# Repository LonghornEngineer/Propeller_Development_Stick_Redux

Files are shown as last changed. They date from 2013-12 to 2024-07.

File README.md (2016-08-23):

LHE_BANNER
***
###Propeller_Development_Stick_Redux
***
**Tiny development board based on the Parallax Propeller.**

More information can be found on the [Propeller Development Stick project page](http://longhornengineer.com/projects/pcb/propeller-development-stick-redux/).

Board Files are for Cadsoft Eagle V6.0+

***
**License Information**

This project is under the [Creative Commons Attribution-ShareAlike 4.0 International License](LICENSE.md). These files are provided with no warranty and should be used at your own risk. 

***

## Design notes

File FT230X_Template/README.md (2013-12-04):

Instructions to flash the FT230X on the Propeller Development Stick.

The FT230X needs to be flashed with the template found on GitHub for the Propeller Development Stick to function correctly.

1. Download and install <a href="http://www.ftdichip.com/Support/Utilities.htm">FT-Prog</a> from FTDI. 

2. Connect the Propeller Development Stick via USB cable and load up FT-Prog.

3. Click "Scan and Parse".

4. Once the FT230X is found right click the name and click "Apply Template". Choose the template you want to apply. 

5. Click "Program Devices"

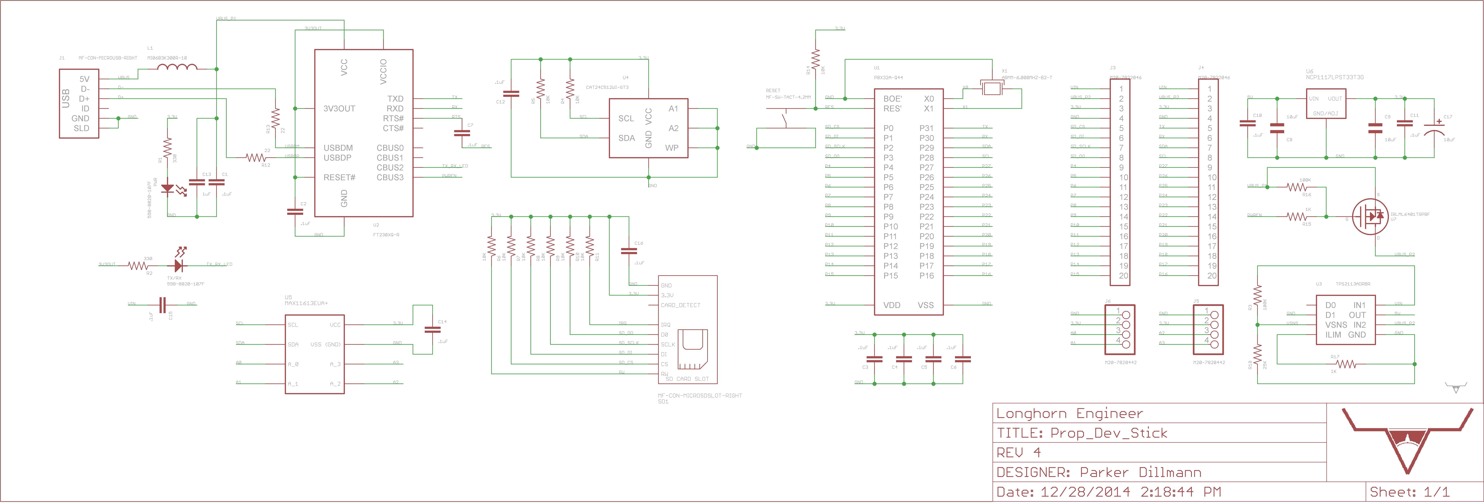
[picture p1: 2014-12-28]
Schematic.png

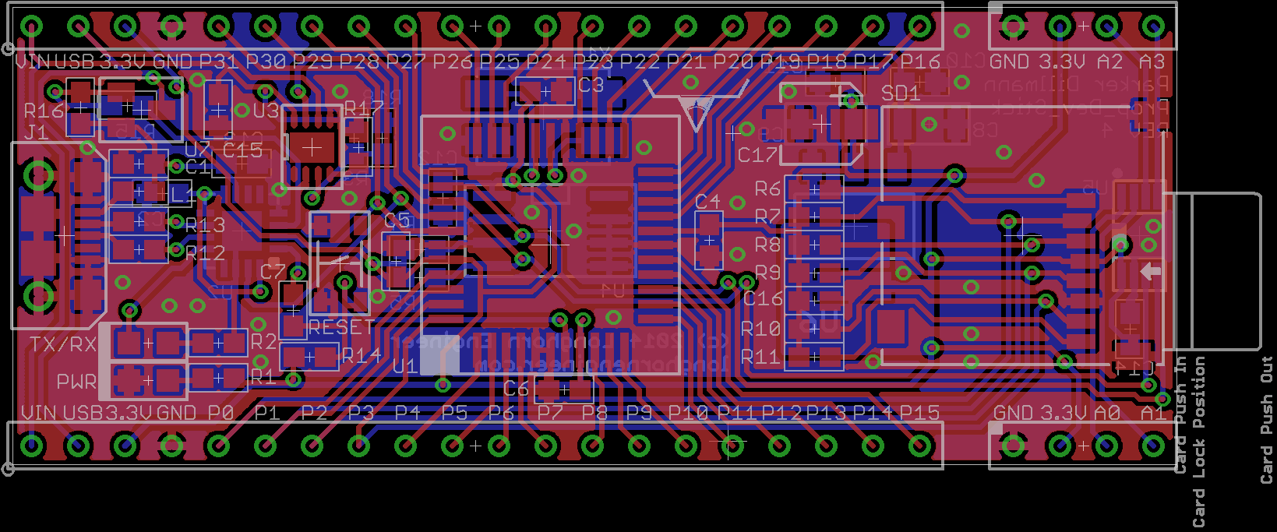
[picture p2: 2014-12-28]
Layout.png

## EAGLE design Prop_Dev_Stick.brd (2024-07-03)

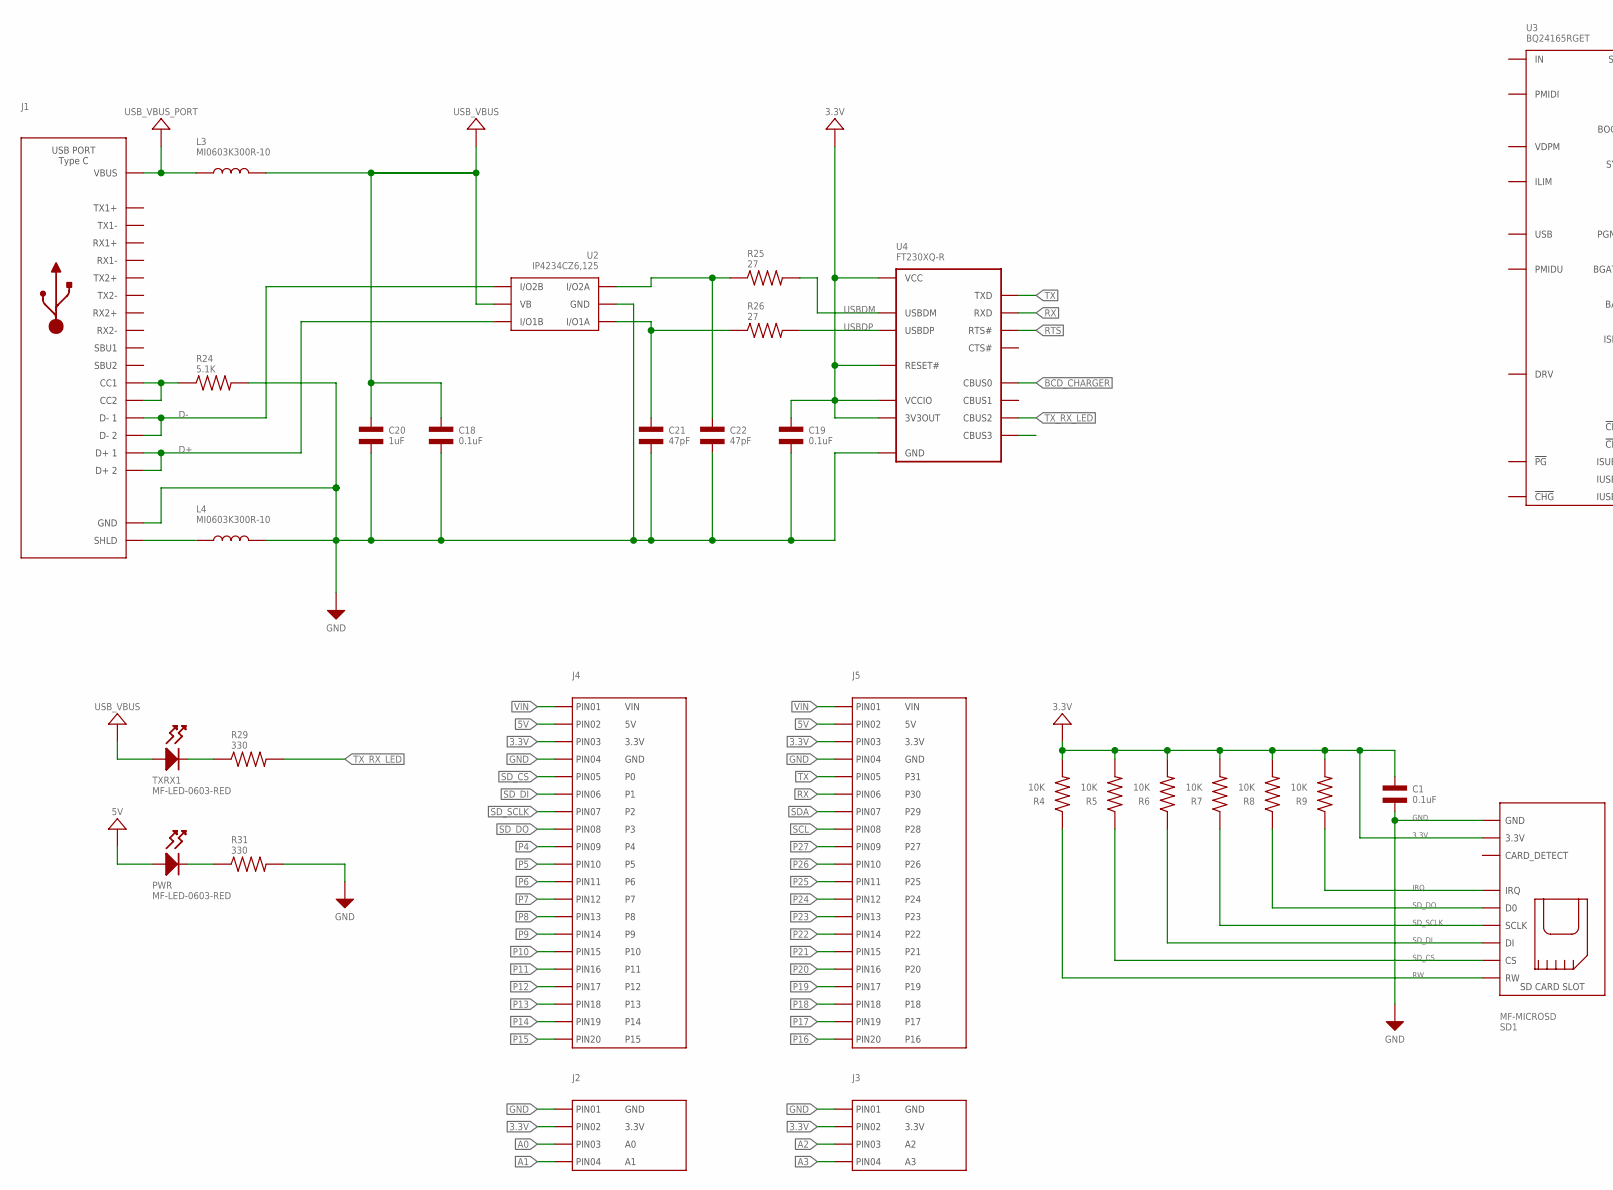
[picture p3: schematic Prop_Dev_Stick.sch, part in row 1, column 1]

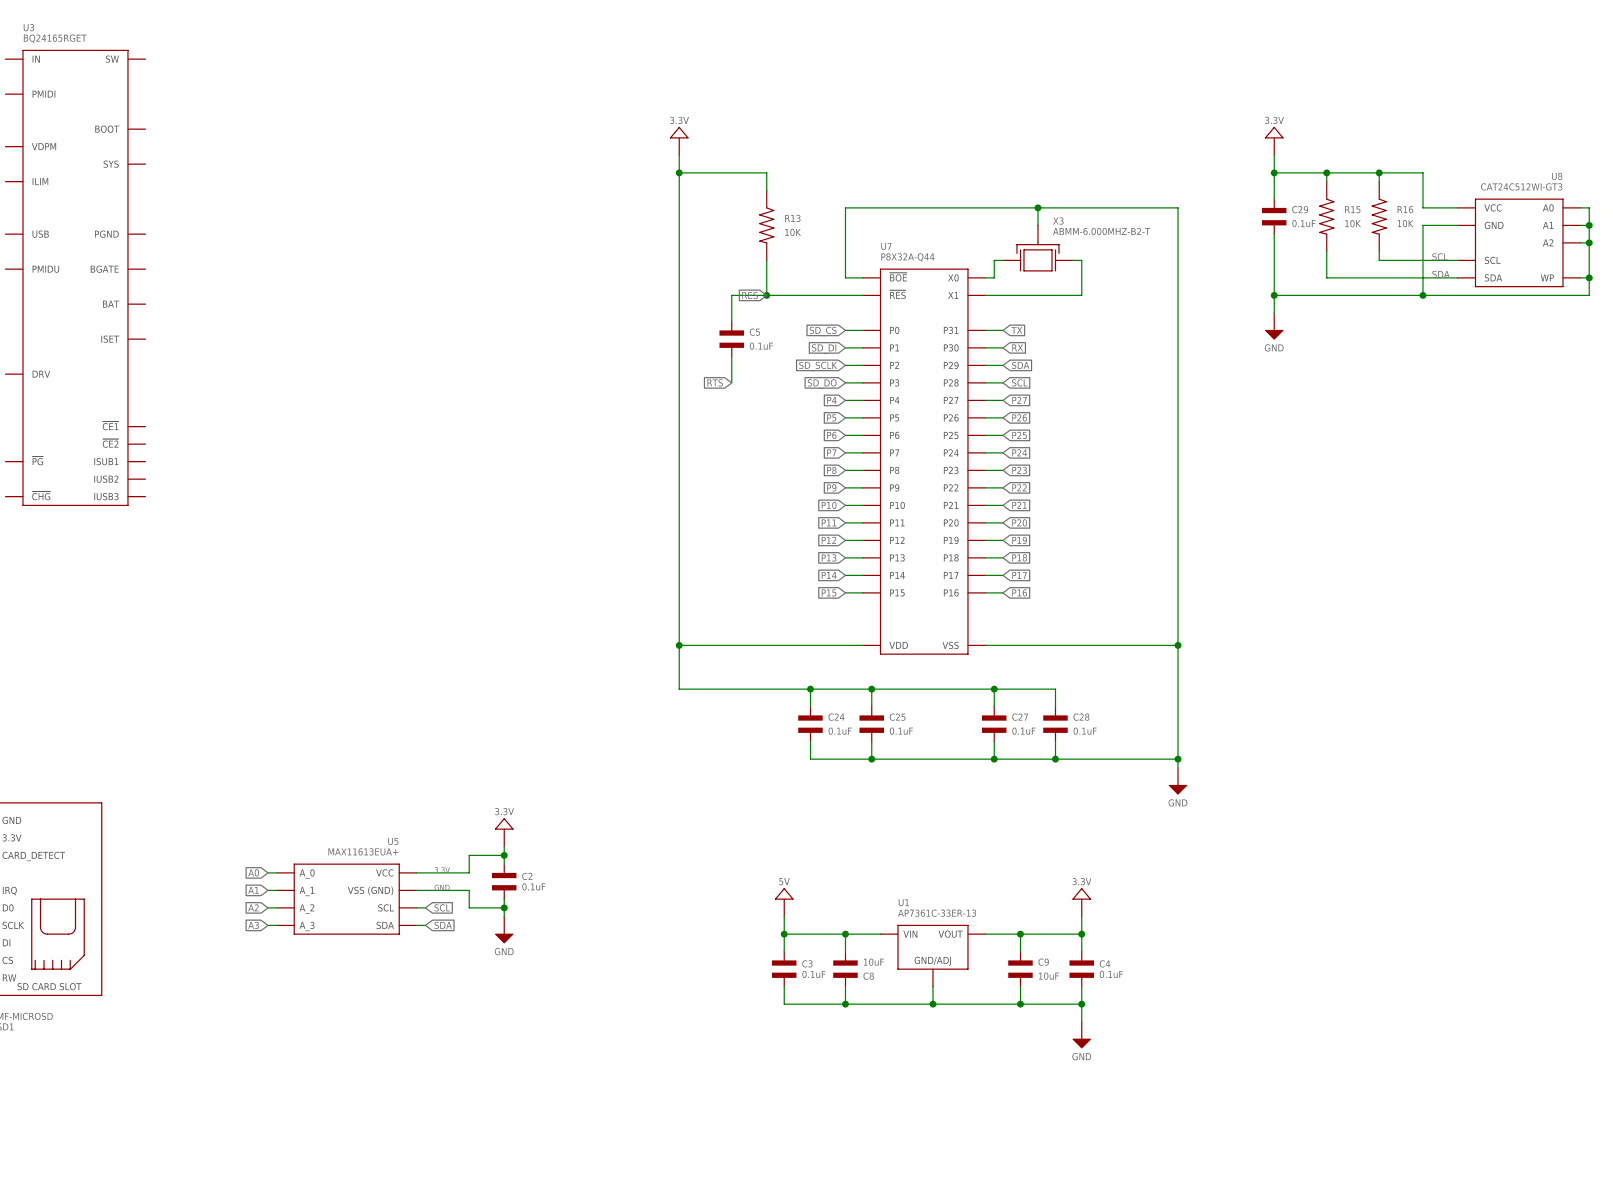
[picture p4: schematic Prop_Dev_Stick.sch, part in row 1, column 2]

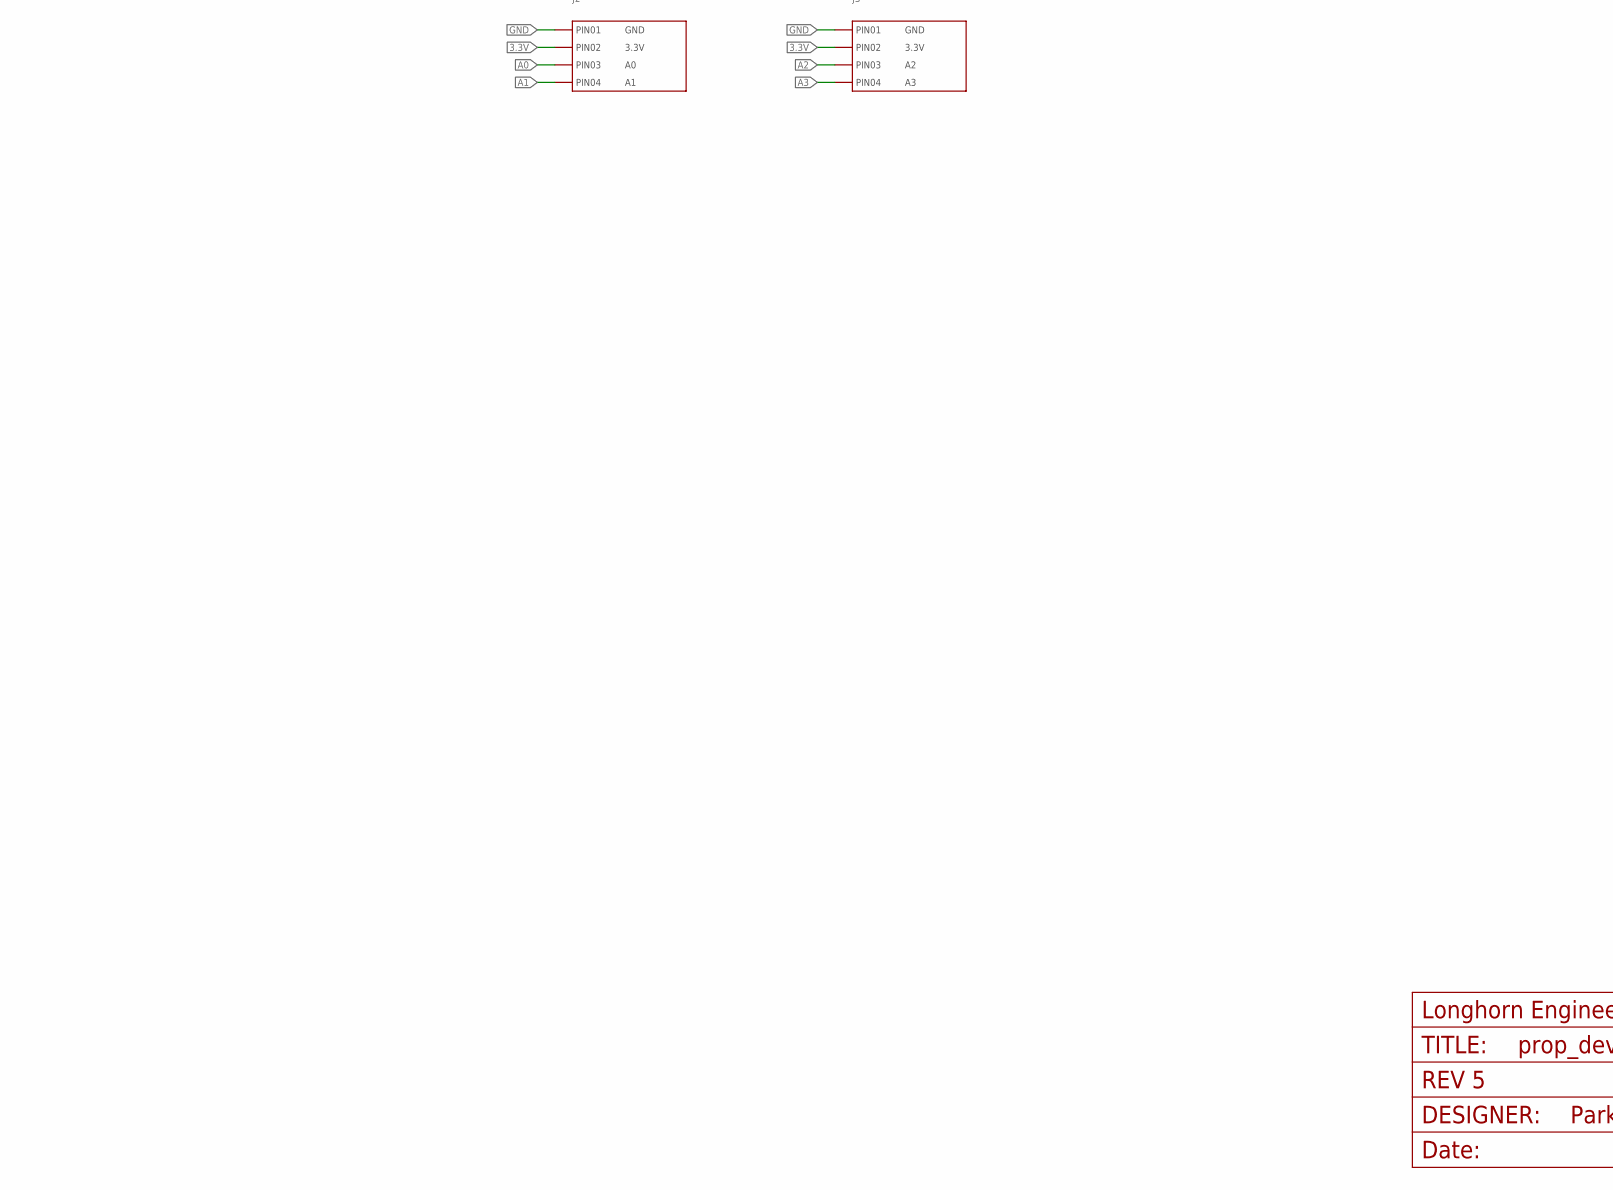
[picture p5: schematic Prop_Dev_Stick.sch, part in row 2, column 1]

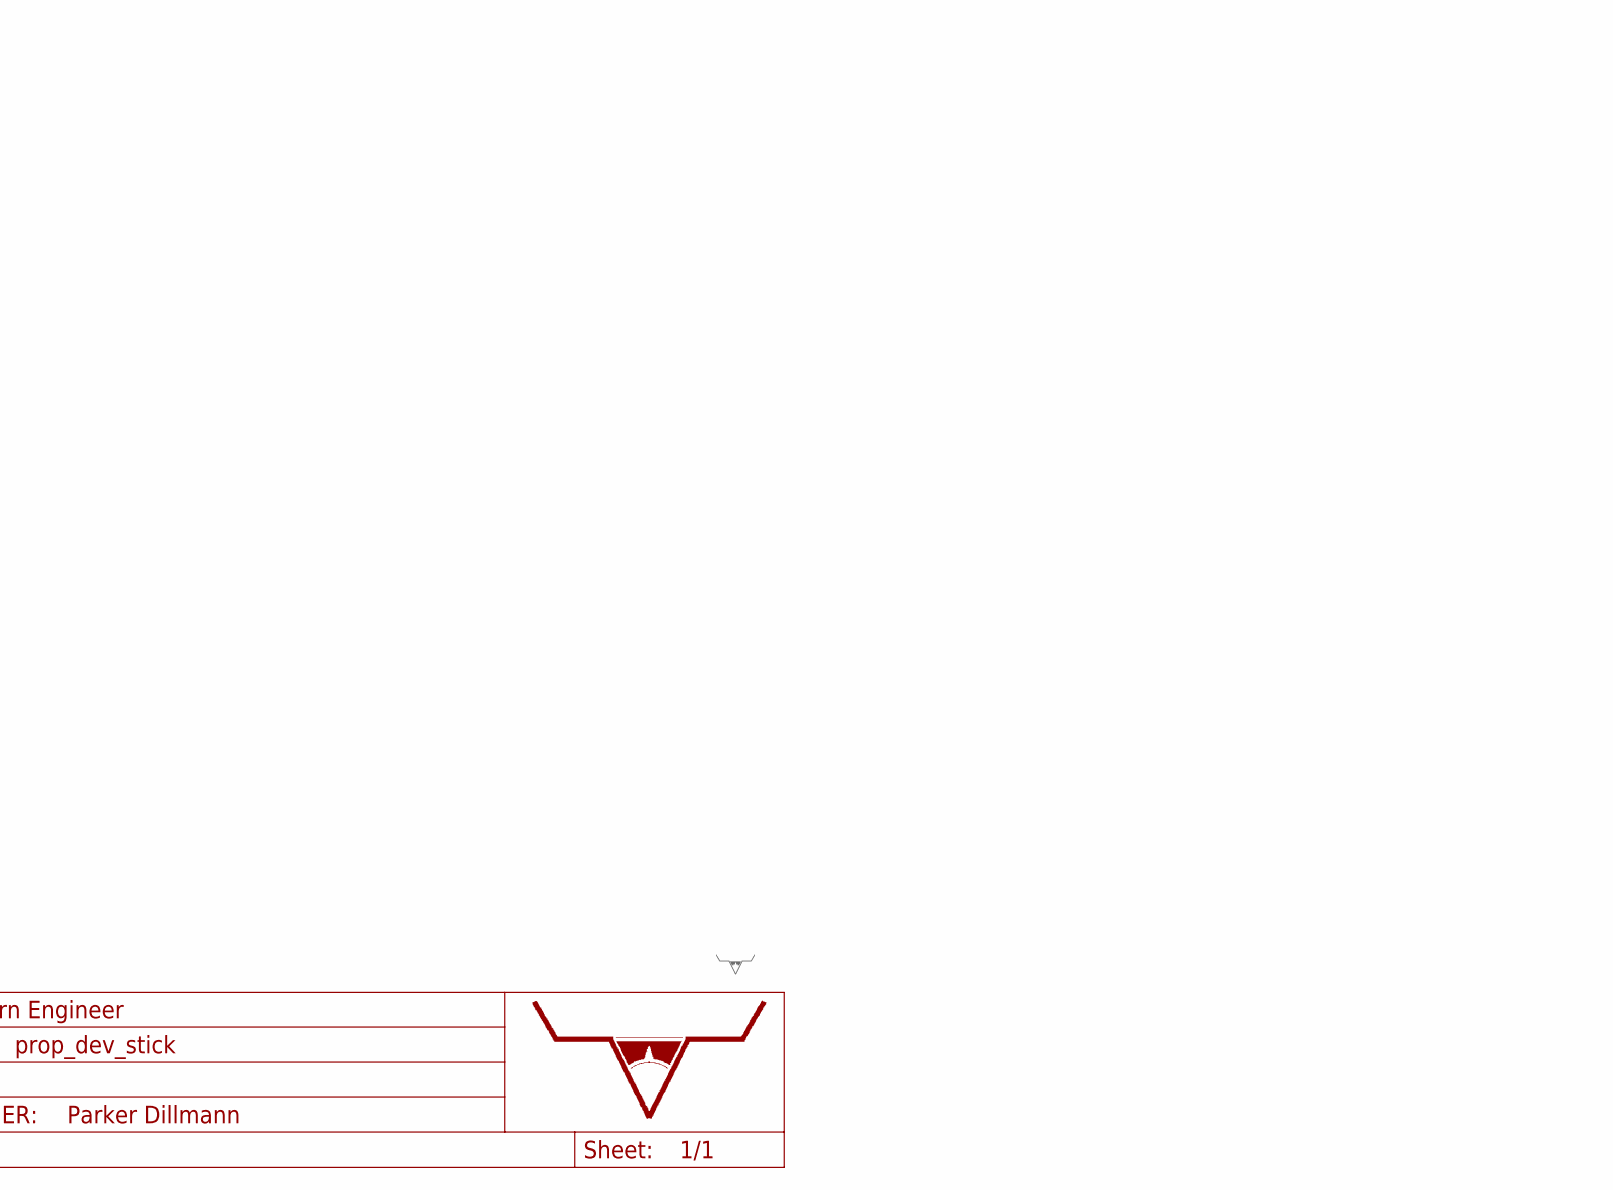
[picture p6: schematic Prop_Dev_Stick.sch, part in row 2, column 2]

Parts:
C1, C2, C3, C4, C18, C19: 0.1uF; C0603
C5, C24, C25, C27, C28, C29: 0.1uF; C0402; MPN MF-CAP-0603-0.1uF
C8, C9: 10uF; C1206
C20: 1uF; C0603
C21, C22: 47pF; C0603
J1: USB_TYPE-C_105450-0101; 105450-0101
J2, J3: CON_01X04_2.54MM_PIN_HEADER; 2.54MM_01X04_PIN_HEADER
J4, J5: CON_01X20_2.54MM_PIN_HEADER; 2.54MM_01X20_PIN_HEADER
L3, L4: MI0603K300R-10; L0603
PWR: MF-LED-0603-RED; LED0603
R4, R5, R6, R7, R8, R9: 10K; R0603
R13: 10K; R0402; MPN MF-RES-0805-10K
R15, R16: 10K; R0402; MPN MF-RES-0603-10K
R24: 5.1K; R0603
R25, R26: 27; R0603
R29, R31: 330; R0402
SD1: MF-MICROSD
TXRX1: MF-LED-0603-RED; LED0603
U1: AP7361C-33ER-13; ADP3338_SOT-223-3
U2: IP4234CZ6,125; IP4234CZ6_SOT-457-6
U3: BQ24165RGET; BQ24165_QFN-24
U4: FT230XQ-R; FT230X_QFN-16
U5: MAX11613EUA+; MAX11613_UMAX-8
U7: P8X32A-Q44; P8X32A_QFN-44; MPN P8X32A-Q44
U8: CAT24C512WI-GT3; SOIC-8_W; MPN CAT24C512WI-GT3
U$1: LHE_FRAME
U$2: LHE_LOGOLHE_LOGO; LHE_LOGO
X3: ABMM-6.000MHZ-B2-T; 7MMX5MM; MPN ABMM-6.000MHZ-B2-T

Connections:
3.3V: C1.P$1, C2.P$1, C4.P$1, C9.P$1, C19.P$1, C24.P$1, C25.P$1, C27.P$1, C28.P$1, C29.P$1, J2.2, J3.2, J4.3, J5.3, R4.P$2, R5.P$2, R6.P$2, R7.P$2, R8.P$2, R9.P$2, R13.P$1, R15.P$1, R16.P$1, SD1.PIN4 (3.3V), U1.2 (OUT), U1.PAD (OUT), U4.1 (VCCIO), U4.8 (3V3OUT), U4.9 (RESET#), U4.10 (VCC), U5.P$8 (VCC), U7.8 (VDD), U7.18 (VDD), U7.30 (VDD), U7.40 (VDD), U8.8 (VCC)
5V: C3.P$1, C8.P$2, J4.2, J5.2, PWR.ANODE, U1.3 (IN)
A0: J2.3, U5.P$1 (A_0)
A1: J2.4, U5.P$2 (A_1)
A2: J3.3, U5.P$3 (A_2)
A3: J3.4, U5.P$4 (A_3)
BCD_CHARGER: U4.12 (CBUS0)
CC1/1: J1.A5 (CC1), J1.B5 (CC2), R24.P$1
D+: J1.A6 (D+1), J1.B6 (D+2), U2.3 (I/O1B)
D-: J1.A7 (D-1), J1.B7 (D-2), U2.4 (I/O2B)
GND: C1.P$2, C2.P$2, C3.P$2, C4.P$2, C8.P$1, C9.P$2, C18.P$2, C19.P$2, C20.P$2, C21.P$2, C22.P$2, C24.P$2, C25.P$2, C27.P$2, C28.P$2, C29.P$2, J1.A1 (GND), J1.A12 (GND), J1.B1 (GND), J1.B12 (GND), J2.1, J3.1, J4.4, J5.4, L4.P$2, R24.P$2, R31.P$2, SD1.G0 (GND), SD1.G1 (GND), SD1.PIN6 (GND), U1.1 (GND), U2.2 (GND), U4.3 (GND), U4.13 (GND), U4.PAD (GND), U5.P$7 (GND), U7.5 (VSS), U7.6 (!BOE), U7.17 (VSS), U7.27 (VSS), U7.39 (VSS), U8.1 (A0), U8.2 (A1), U8.3 (A2), U8.4 (GND), U8.7 (WP), X3.P$2 (GND), X3.P$4 (GND)
IRQ: R9.P$1, SD1.PIN8 (IRQ)
unnamed: R29.P$1, TXRX1.CATHODE
unnamed: PWR.CATHODE, R31.P$1
unnamed: J1.S_T1 (SHLD), J1.S_T2 (SHLD), J1.S_T3 (SHLD), J1.S_T4 (SHLD), L4.P$1
unnamed: C21.P$1, R26.P$1, U2.1 (I/O1A)
unnamed: C22.P$1, R25.P$1, U2.6 (I/O2A)
P4: J4.9, U7.1 (P4)
P5: J4.10, U7.2 (P5)
P6: J4.11, U7.3 (P6)
P7: J4.12, U7.4 (P7)
P8: J4.13, U7.9 (P8)
P9: J4.14, U7.10 (P9)
P10: J4.15, U7.11 (P10)
P11: J4.16, U7.12 (P11)
P12: J4.17, U7.13 (P12)
P13: J4.18, U7.14 (P13)
P14: J4.19, U7.15 (P14)
P15: J4.20, U7.16 (P15)
P16: J5.20, U7.19 (P16)
P17: J5.19, U7.20 (P17)
P18: J5.18, U7.21 (P18)
P19: J5.17, U7.22 (P19)
P20: J5.16, U7.23 (P20)
P21: J5.15, U7.24 (P21)
P22: J5.14, U7.25 (P22)
P23: J5.13, U7.26 (P23)
P24: J5.12, U7.31 (P24)
P25: J5.11, U7.32 (P25)
P26: J5.10, U7.33 (P26)
P27: J5.9, U7.34 (P27)
RES: C5.P$1, R13.P$2, U7.7 (!RES)
RTS: C5.P$2, U4.16 (RTS#)
RW: R4.P$1, SD1.PIN1 (RW)
RX: J5.6, U4.2 (RXD), U7.37 (P30)
SCL: J5.8, R16.P$2, U5.P$5 (SCL), U7.35 (P28), U8.6 (SCL)
SDA: J5.7, R15.P$2, U5.P$6 (SDA), U7.36 (P29), U8.5 (SDA)
SD_CS: J4.5, R5.P$1, SD1.PIN2 (CS), U7.41 (P0)
SD_DI: J4.6, R6.P$1, SD1.PIN3 (DI), U7.42 (P1)
SD_DO: J4.8, R8.P$1, SD1.PIN7 (D0), U7.44 (P3)
SD_SCLK: J4.7, R7.P$1, SD1.PIN5 (SCLK), U7.43 (P2)
TX: J5.5, U4.15 (TXD), U7.38 (P31)
TX_RX_LED: R29.P$2, U4.5 (CBUS2)
USBDM: R25.P$2, U4.7 (USBDM)
USBDP: R26.P$2, U4.6 (USBDP)
USB_VBUS: C18.P$1, C20.P$1, L3.P$2, TXRX1.ANODE, U2.5 (VB)
USB_VBUS_PORT: J1.A4 (VBUS), J1.A9 (VBUS), J1.B4 (VBUS), J1.B9 (VBUS), L3.P$1
VIN: J4.1, J5.1
X4: U7.29 (X0), X3.P$3 (X1)
X5: U7.28 (X1), X3.P$1 (X0)

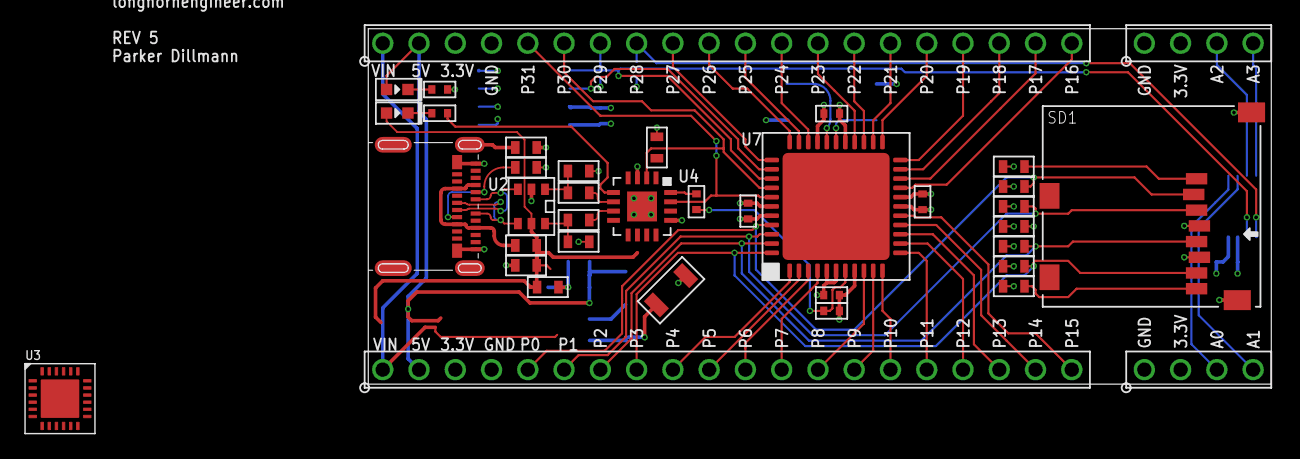
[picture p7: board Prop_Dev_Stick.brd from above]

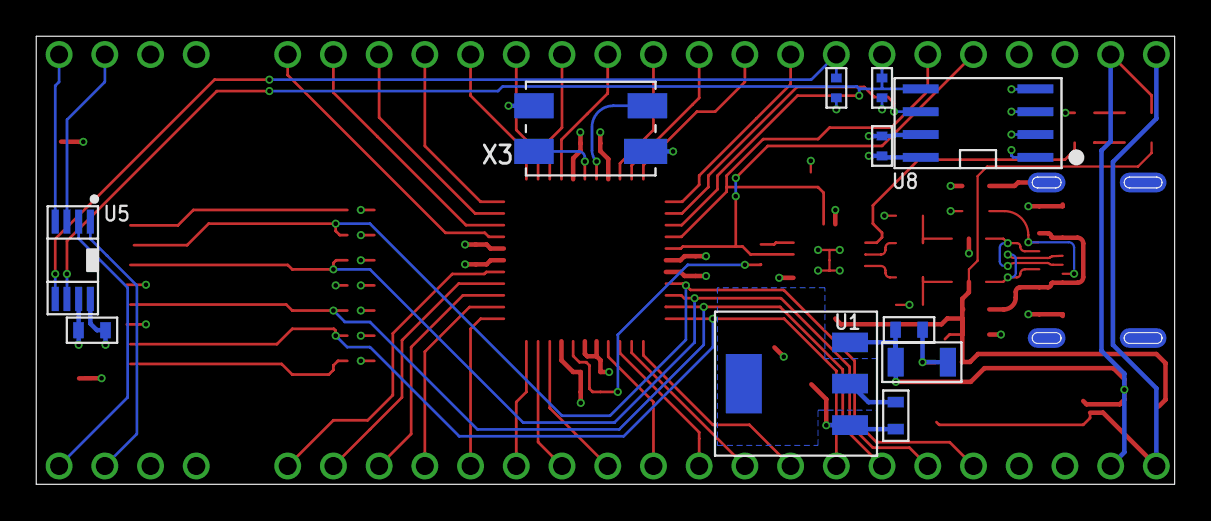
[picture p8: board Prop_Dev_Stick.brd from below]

Board: 4 copper layers, 63.2 x 24.9 mm, 51 parts (11 on the bottom side), 59 nets.

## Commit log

2013-10-22 Push of REV_2 files
    [Prop_Dev_Stick.brd, Prop_Dev_Stick.sch]
2013-12-04 Added PropGcc Template files
    [PropDevStick.cfg]
2013-12-04 Fixed Values on a couple parts. Added BOM.txt
    [Prop_Dev_Stick.brd, Prop_Dev_Stick.sch]
2013-12-04 added description for board files.
2013-12-04 Changed silkscreen error.
    [Prop_Dev_Stick.brd]
2013-12-05 Added PDS_Panel
    [PDS_Panel.brd]
2013-12-16 Adjusted edge of board to remove DRC issues.
    [Prop_Dev_Stick.brd]
2014-01-21 Uploading Schematic.png
2014-11-07 Removing Panel files.
    [PDS_Panel.brd]
2014-11-07 Finished REV3!!!
    [Prop_Dev_Stick.brd, Prop_Dev_Stick.sch]
2014-12-16 Added power switching for LDO Voltage Dropout.
    [Prop_Dev_Stick.brd, Prop_Dev_Stick.sch]
2014-12-17 Changed SD Card Slot.
    [Prop_Dev_Stick.brd, Prop_Dev_Stick.sch]
2014-12-17 Changed USB connector
    [Prop_Dev_Stick.brd, Prop_Dev_Stick.sch]
2014-12-22 Routed power switching for LDO dropout
    [Prop_Dev_Stick.brd, Prop_Dev_Stick.sch]
2014-12-23 Changed crystal.
    [Prop_Dev_Stick.brd, Prop_Dev_Stick.sch]
2014-12-28 REV 4 push
    New SD Card, MAX ADC, added 10uF cap.
    [Prop_Dev_Stick.brd, Prop_Dev_Stick.sch]
2014-12-29 Added paste to USB connector shield hole.
    [Prop_Dev_Stick.brd, Prop_Dev_Stick.sch]
2015-12-17 Updated design to use latest library style!
    [Prop_Dev_Stick.brd, Prop_Dev_Stick.sch]
2015-12-17 Updated to REV 4B
    [Prop_Dev_Stick.brd, Prop_Dev_Stick.sch]
2016-02-17 REV 4B
    [Prop_Dev_Stick.brd, Prop_Dev_Stick.sch]
2019-01-15 Working on REV5
    REV5 will feature 0402 parts, QFN Prop, USB Type-C, and a host of other
    small changes.
    [Prop_Dev_Stick.brd, Prop_Dev_Stick.sch]
2024-07-03 pushing updates from long ago
    [PropDevStick.cfg, Prop_Dev_Stick.brd, Prop_Dev_Stick.sch]

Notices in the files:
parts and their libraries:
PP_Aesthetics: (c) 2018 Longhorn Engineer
